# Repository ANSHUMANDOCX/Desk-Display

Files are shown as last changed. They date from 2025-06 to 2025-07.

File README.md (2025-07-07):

# Desk-Display

It is a desk display made using an E-Ink display.

---

## PARTS

I will be using the following components:

- SEEKINK 5.83 inch display  
- ESP32 WROOM  
- CH343P USB-UART  

---

## Plan

I want to make a display that can show anything, but for me, I want it to display the current **day**, **date**, and **time**, along with a **To-Do list** at the bottom.

What I want to do is have the program fetch the day, date, and time details from the Wi-Fi network the ESP32 is connected to. For the To-Do list, I will use a **website hosted on the ESP32 server** to update the data whenever I want.

The display won't be battery powered — although it can be — but I don't want that for now. It will be powered through **USB-C**. For that, I’ve also added a **switch** to disconnect the board from programming mode by turning off the CH343 IC.

# Schematic,PCB and CAD







# BOM 
---
| Product Name | Retailer | Price ($) |
|---|---|---|
| E-ink Display | LCSC | 18.16 |
| FFC, FPC Connector | LCSC | 0.79 |
| MOSFET (SI2301CDS-T1-E3) | LCSC | 0.77 |
| DIP Switch | LCSC | 0.72 |
| LDO Regulator (RT9193-33GB) | LCSC | 0.54 |
| USB to UART Converter | LCSC | 1.13 |
| WiFi Module (ESP32-WROOM-32E-N4) | LCSC | 3.89 |
| Passive Components (Grouped) | LCSC | 5.08 |
| **Subtotal (Merchandise)** | **LCSC** | **31.51** |
| Shipping | LCSC | 3.73 |
| **Total** | **LCSC** | **35.24** |
|PCB | JLCPCB | 2$ |
|Shipping |JLCPCB | 8.32$ |
|Solder Paste+ Tweezers |Electronicscomp |5$ |
| **SUB TOTAL** | |**50.56**  |

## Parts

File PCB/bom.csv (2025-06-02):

Designator | Footprint | Quantity | Value | LCSC Part #
C10, C11, C12, C13, C15, C16, C2, C5, C7, C9 | 0603 | 10 | 1UF
C14, C20, C23, C4 | 0603 | 4 | 10uF
C17, C19, C6 | 0603 | 3 | 4.7uf
C18 | 0603 | 1 | 104
C21 | 0603 | 1 | 22nF
C22 | 0603 | 1 | 47uF
C3 | 0603 | 1 | C_Small
D1, D2, D4 | D_SOD-123 | 3 | MBR0530
D3 | D_SOD-323 | 1 | 1N5819WS
D5, D6 | 0805 | 2 | LED
J3 | Hirose_FH12-24S-0.5SH_1x24-1MP_P0.50mm_Horizontal | 1 | Conn_01x24
J4 | USB_C_Receptacle_XKB_U262-16XN-4BVC11 | 1 | USB_C_Receptacle_USB2.0_16P
L1 | L_Changjiang_FNR4020S | 1 | 10uH
Q1 | SOT-23 | 1 | BSS138LT1G
Q2, Q3, Q32 | SOT-23 | 3 | SS8050
Q31 | SOT-23 | 1 | SI2301CDS-T1-E3
R1 | 0603 | 1 | 1k
R10, R35 | 0603 | 2 | NC
R11, R12, R15 | 0603 | 3 | 0r
R13, R14, R19, R3, R4, R5, R6, R8, R9 | 0603 | 9 | 10K
R16, R17 | 0603 | 2 | 5.1K
R2 | 0603 | 1 | 2.2k
R33, R34 | 0603 | 2 | 100K
R7 | 0603 | 1 | 0.47R
SW2 | SW_DIP_SPSTx02_Slide_Copal_CHS-02B_W7.62mm_P1.27mm | 1 | SW_Push_Dual_x2
SW3, SW4 | SW_Push_SPST_NO_Alps_SKRK | 2 | SW_Push
U1 | ESP32-WROOM-32D | 1 | ESP32-WROOM-32E
U2 | WCH_QFN-16-1EP_3x3mm_P0.5mm_EP1.8x1.8mm | 1 | CH343P
U3 | SOT-23-5 | 1 | RT9193-33
U4 | SOT-23-5 | 1 | ME6217C33M5G

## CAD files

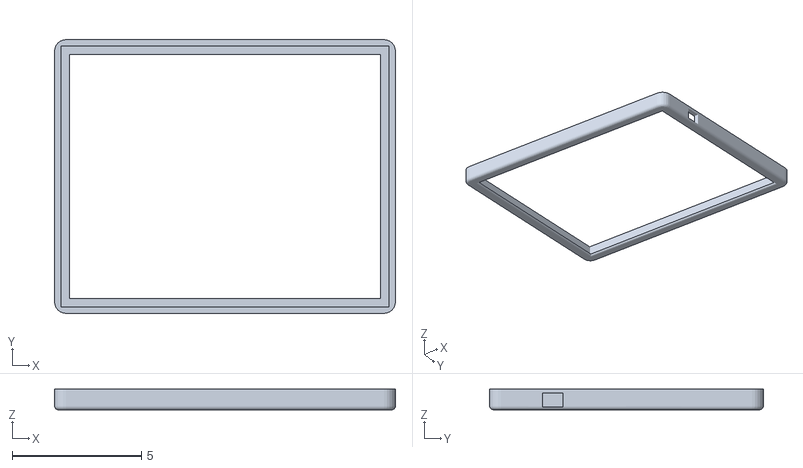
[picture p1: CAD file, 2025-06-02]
CAD/Main boy v2.obj
13.2 x 10.6 x 0.8

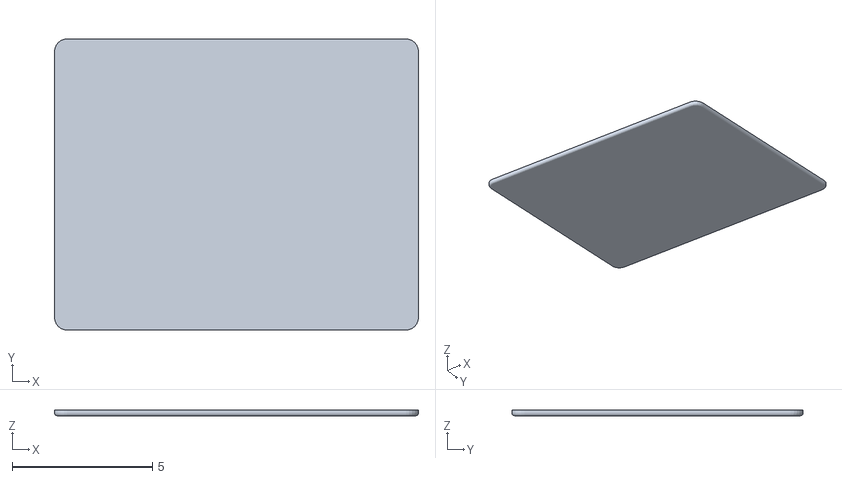
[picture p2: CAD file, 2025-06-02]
CAD/BackPLate v1.obj
13.0 x 10.4 x 0.2

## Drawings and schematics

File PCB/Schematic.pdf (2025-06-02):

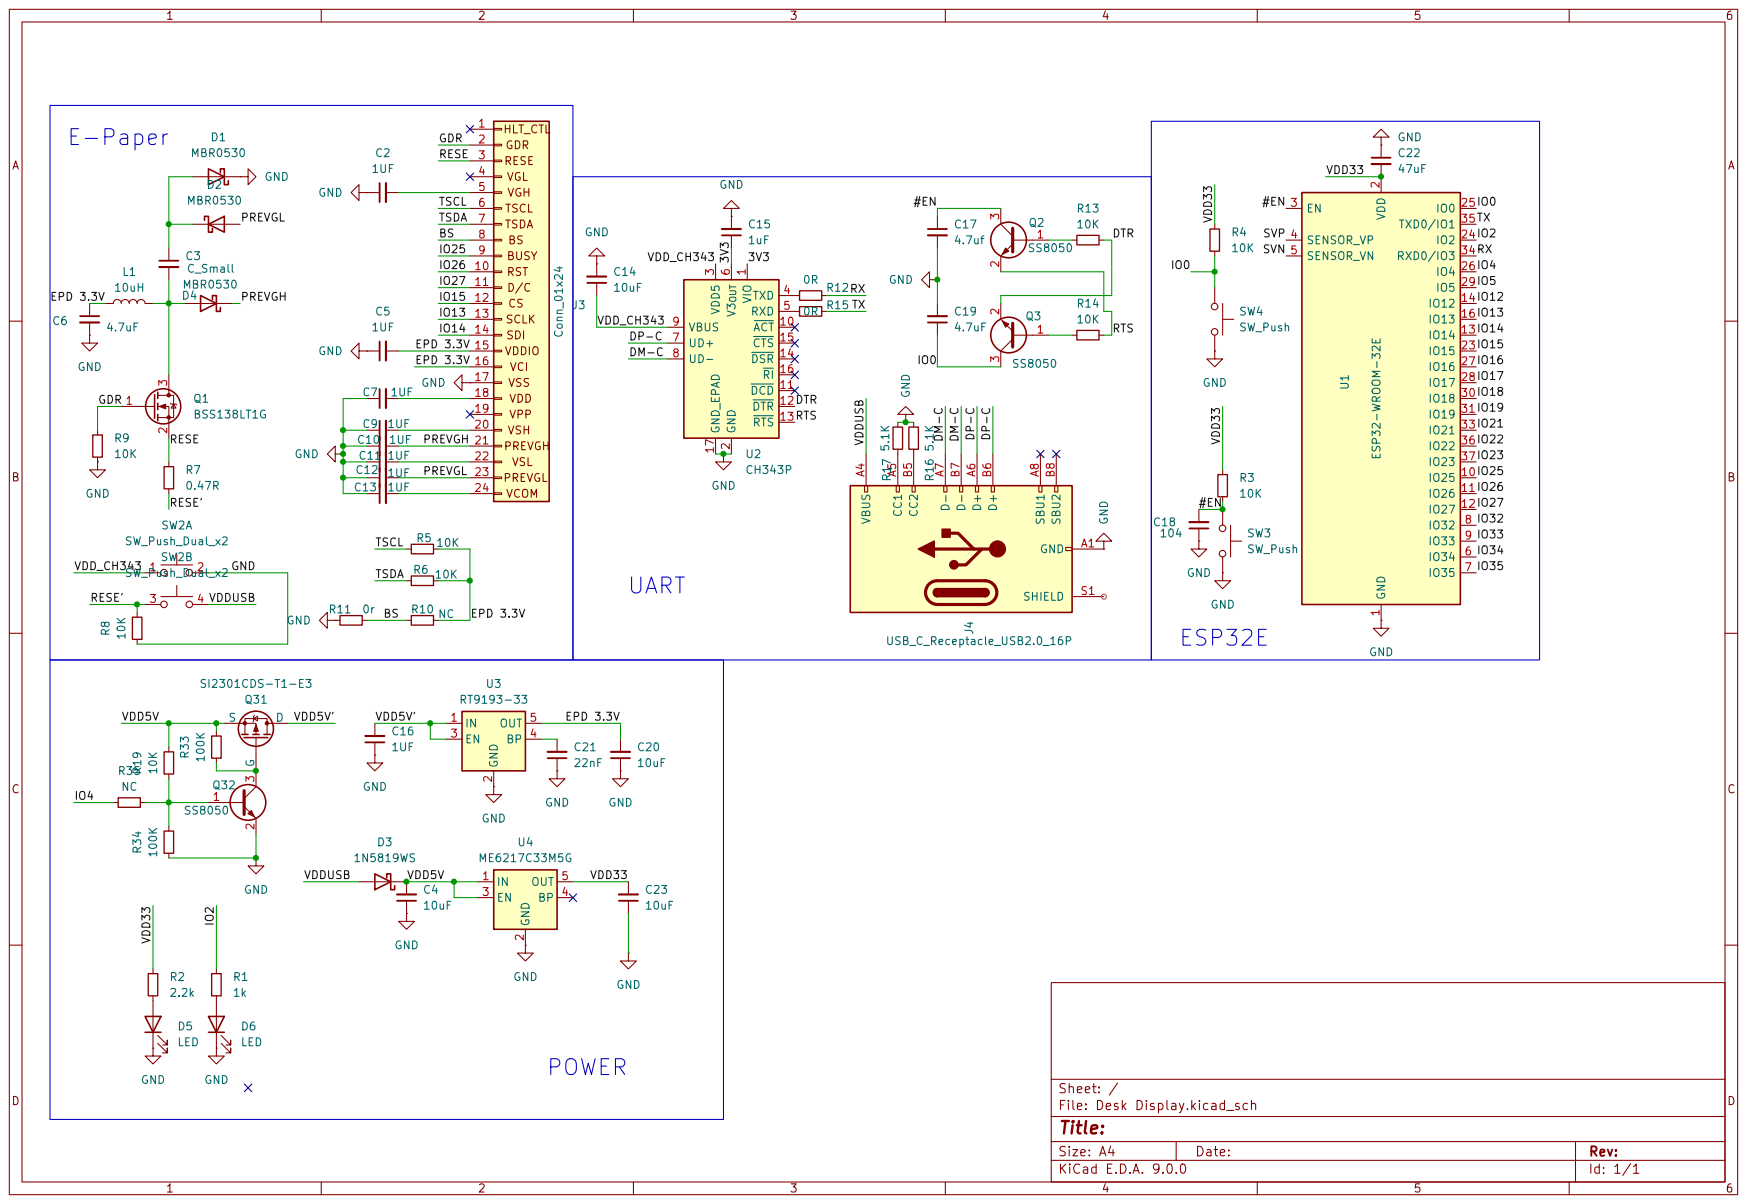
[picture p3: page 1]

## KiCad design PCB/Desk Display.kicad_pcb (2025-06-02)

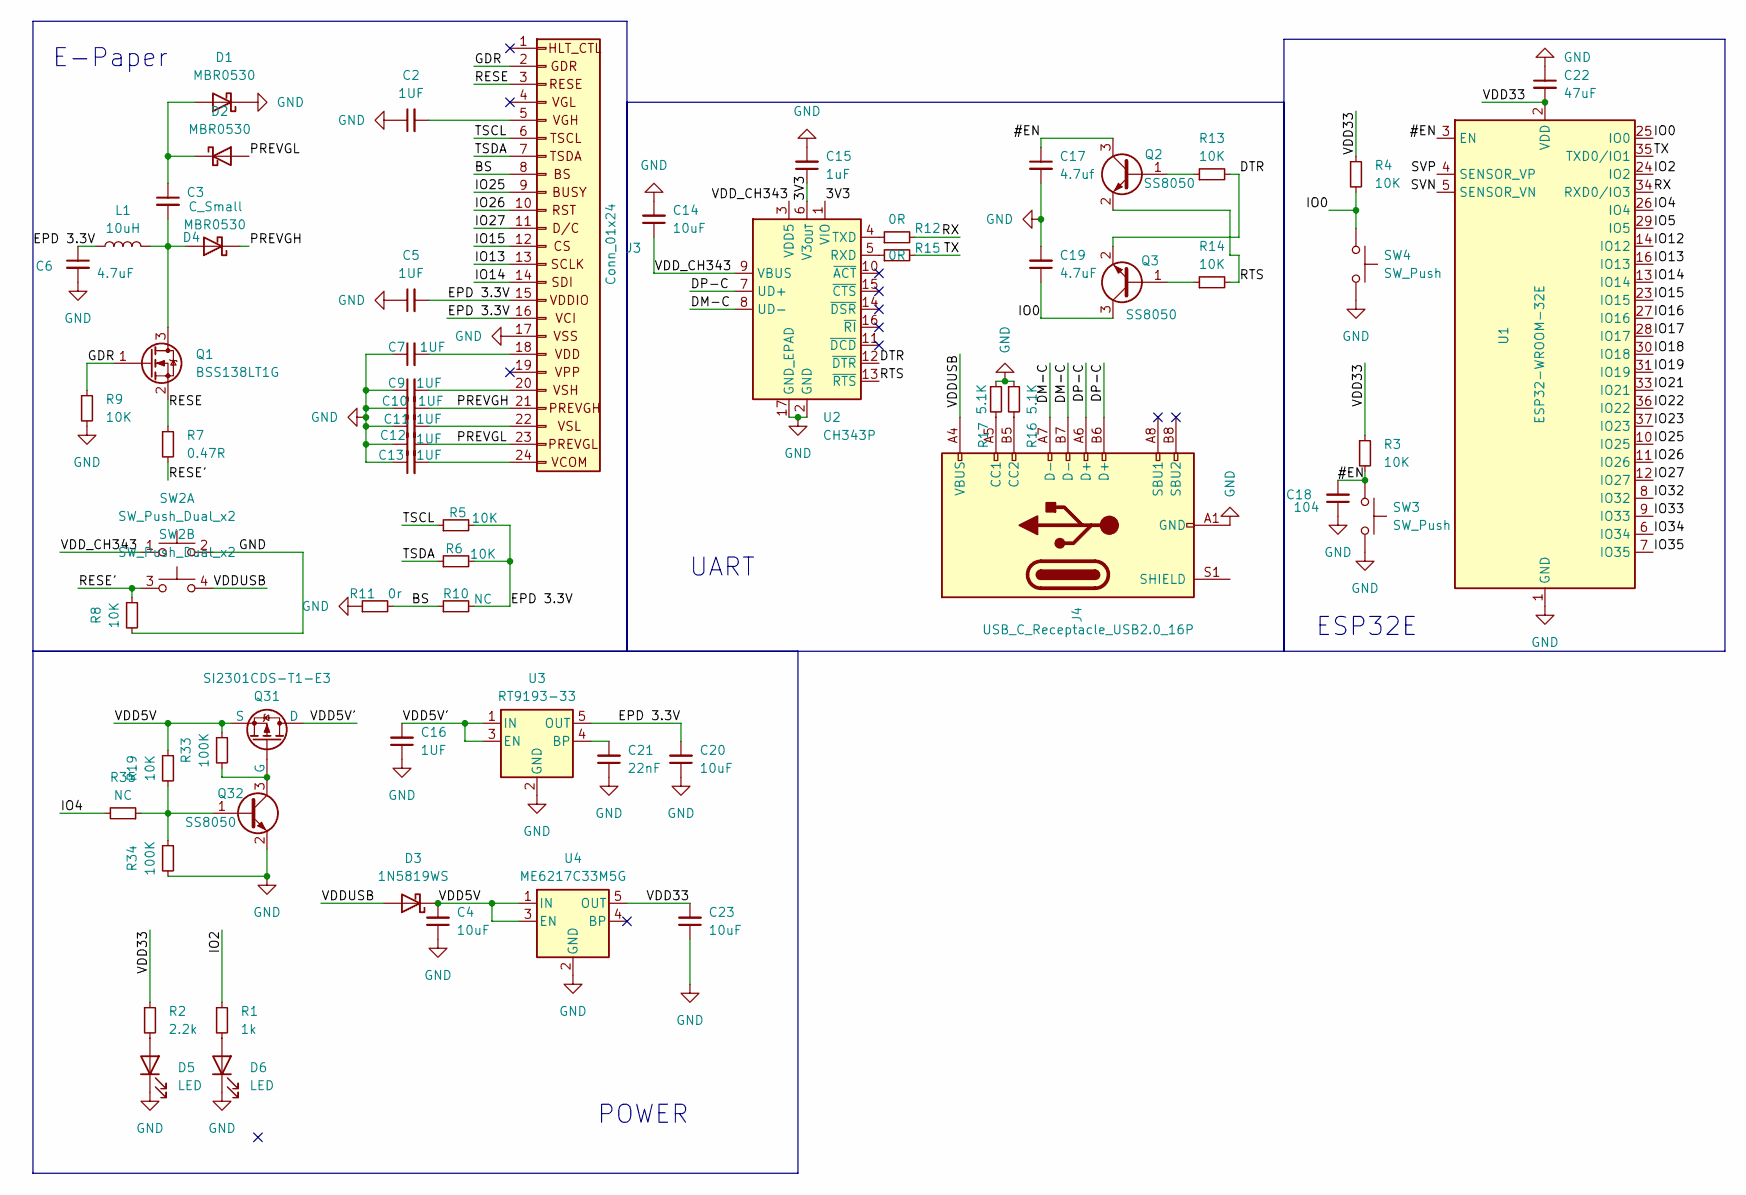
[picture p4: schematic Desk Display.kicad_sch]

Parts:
C2, C5, C7, C9, C10, C11, C12, C13, C16: 1UF; C_0603_1608Metric_Pad1.08x0.95mm_HandSolder
C3: C_Small; C_0603_1608Metric_Pad1.08x0.95mm_HandSolder
C4, C14, C20, C23: 10uF; C_0603_1608Metric_Pad1.08x0.95mm_HandSolder
C6, C19: 4.7uF; C_0603_1608Metric_Pad1.08x0.95mm_HandSolder
C15: 1uF; C_0603_1608Metric_Pad1.08x0.95mm_HandSolder
C17: 4.7uf; C_0603_1608Metric_Pad1.08x0.95mm_HandSolder
C18: 104; C_0603_1608Metric_Pad1.08x0.95mm_HandSolder
C21: 22nF; C_0603_1608Metric_Pad1.08x0.95mm_HandSolder
C22: 47uF; C_0603_1608Metric_Pad1.08x0.95mm_HandSolder
D1, D2, D4: MBR0530; D_SOD-123
D3: 1N5819WS; D_SOD-323
D5, D6: LED; LED_0805_2012Metric_Pad1.15x1.40mm_HandSolder
J3: Conn_01x24; Hirose_FH12-24S-0.5SH_1x24-1MP_P0.50mm_Horizontal
J4: USB_C_Receptacle_USB2.0_16P; USB_C_Receptacle_XKB_U262-16XN-4BVC11
L1: 10uH; L_Changjiang_FNR4020S
Q1: BSS138LT1G; SOT-23
Q2, Q3, Q32: SS8050; SOT-23
Q31: SI2301CDS-T1-E3; SOT-23
R1: 1k; R_0603_1608Metric_Pad0.98x0.95mm_HandSolder
R2: 2.2k; R_0603_1608Metric_Pad0.98x0.95mm_HandSolder
R3, R4, R5, R6, R8, R9, R13, R14, R19: 10K; R_0603_1608Metric_Pad0.98x0.95mm_HandSolder
R7: 0.47R; R_0603_1608Metric_Pad0.98x0.95mm_HandSolder
R10, R35: NC; R_0603_1608Metric_Pad0.98x0.95mm_HandSolder
R11: 0r; R_0603_1608Metric_Pad0.98x0.95mm_HandSolder
R12, R15: 0R; R_0603_1608Metric_Pad0.98x0.95mm_HandSolder
R16, R17: 5.1K; R_0603_1608Metric_Pad0.98x0.95mm_HandSolder
R33, R34: 100K; R_0603_1608Metric_Pad0.98x0.95mm_HandSolder
SW2: SW_Push_Dual_x2; SW_DIP_SPSTx02_Slide_Copal_CHS-02B_W7.62mm_P1.27mm
SW3, SW4: SW_Push; SW_Push_SPST_NO_Alps_SKRK
U1: ESP32-WROOM-32E; ESP32-WROOM-32D
U2: CH343P; WCH_QFN-16-1EP_3x3mm_P0.5mm_EP1.8x1.8mm
U3: RT9193-33; SOT-23-5
U4: ME6217C33M5G; SOT-23-5

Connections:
/3V3: C15.1, U2.1 (VIO), U2.6 (V3_{OUT})
/#EN: C17.1, C18.2, Q2.3 (C), R3.2, SW3.1, U1.3 (EN)
/BS: J3.8, R10.1, R11.2
/DM-C: J4.A7 (D-), J4.B7 (D-), U2.8 (UD-)
/DP-C: J4.A6 (D+), J4.B6 (D+), U2.7 (UD+)
/DTR: Q3.2 (E), R13.2, U2.12 (~DTR)
/EPD 3.3V: C5.2, C6.1, C20.2, J3.15, J3.16, L1.1, R5.2, R6.2, R10.2, U3.5 (OUT)
/GDR: J3.2, Q1.1 (G), R9.1
/IO0: C19.1, Q3.3 (C), R4.2, SW4.1, U1.25 (IO0)
/IO2: R1.1, U1.24 (IO2)
/IO4: R35.2, U1.26 (IO4)
/IO5: U1.29 (IO5)
/IO12: U1.14 (IO12)
/IO13: J3.13, U1.16 (IO13)
/IO14: J3.14, U1.13 (IO14)
/IO15: J3.12, U1.23 (IO15)
/IO16: U1.27 (IO16)
/IO17: U1.28 (IO17)
/IO18: U1.30 (IO18)
/IO19: U1.31 (IO19)
/IO21: U1.33 (IO21)
/IO22: U1.36 (IO22)
/IO23: U1.37 (IO23)
/IO25: J3.9, U1.10 (IO25)
/IO26: J3.10, U1.11 (IO26)
/IO27: J3.11, U1.12 (IO27)
/IO32: U1.8 (IO32)
/IO33: U1.9 (IO33)
/IO34: U1.6 (IO34)
/IO35: U1.7 (IO35)
/PREVGH: C10.2, D4.1 (K), J3.21
/PREVGL: C12.2, D2.2 (A), J3.23
/RESE: J3.3, Q1.2 (S), R7.1
/RESE': R7.2, R8.1, SW2.3 (C)
/RTS: Q2.2 (E), R14.2, U2.13 (~RTS)
/RX: R12.2, U1.34 (RXD0/IO3)
/SVN: U1.5 (SENSOR_VN)
/SVP: U1.4 (SENSOR_VP)
/TSCL: J3.6, R5.1
/TSDA: J3.7, R6.1
/TX: R15.2, U1.35 (TXD0/IO1)
/VDD5V: C4.2, D3.1 (K), Q31.3 (S), R19.1, R33.1, U4.1 (IN), U4.3 (EN)
/VDD5V': C16.2, Q31.1 (D), U3.1 (IN), U3.3 (EN)
/VDD33: C22.2, C23.2, R2.1, R3.1, R4.1, U1.2 (VDD), U4.5 (OUT)
/VDDUSB: D3.2 (A), J4.A4 (VBUS), J4.A9 (VBUS), J4.B4 (VBUS), J4.B9 (VBUS), SW2.4 (D)
/VDD_CH343: C14.1, SW2.1 (C), U2.3 (VDD5), U2.9 (VBUS)
GND: C2.1, C4.1, C5.1, C6.2, C7.1, C9.1, C10.1, C11.1, C12.1, C13.1, C14.2, C15.2, C16.1, C17.2, C18.1, C19.2, C20.1, C21.1, C22.1, C23.1, D1.1 (K), D5.1 (K), D6.1 (K), J3.17, J4.A1 (GND), J4.A12 (GND), J4.B1 (GND), J4.B12 (GND), Q32.2 (E), R8.2, R9.2, R11.1, R16.1, R17.1, R34.2, SW2.2 (D), SW3.2, SW4.2, U1.1 (GND), U1.15 (GND), U1.38 (GND), U1.39 (GND), U2.2 (GND), U2.17 (GND_EPAD), U3.2 (GND), U4.2 (GND)
unnamed: C3.1, D1.2 (A), D2.1 (K)
unnamed: C3.2, D4.2 (A), L1.2, Q1.3 (D)
unnamed: D5.2 (A), R2.2
unnamed: D6.2 (A), R1.2
unnamed: C2.2, J3.5
unnamed: C7.2, J3.18
unnamed: C9.2, J3.20
unnamed: C11.2, J3.22
unnamed: C13.2, J3.24
unnamed: J4.A5 (CC1), R17.2
unnamed: J4.B5 (CC2), R16.2
unnamed: Q2.1 (B), R13.1
unnamed: Q3.1 (B), R14.1
unnamed: Q31.2 (G), Q32.3 (C), R33.2
unnamed: Q32.1 (B), R19.2, R34.1, R35.1
unnamed: R15.1, U2.5 (RXD)
unnamed: R12.1, U2.4 (TXD)
unnamed: C21.2, U3.4 (BP)

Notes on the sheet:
UART
POWER
ESP32E
E-Paper

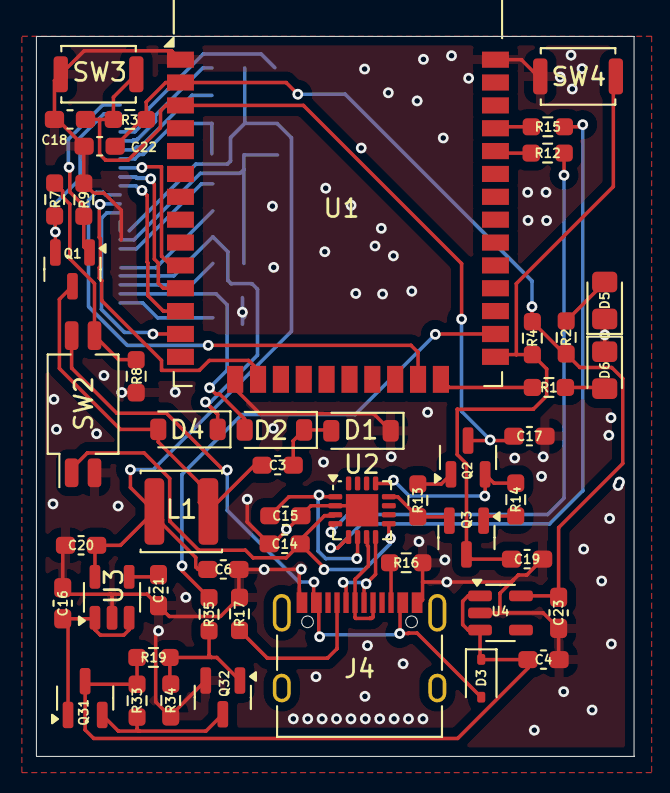
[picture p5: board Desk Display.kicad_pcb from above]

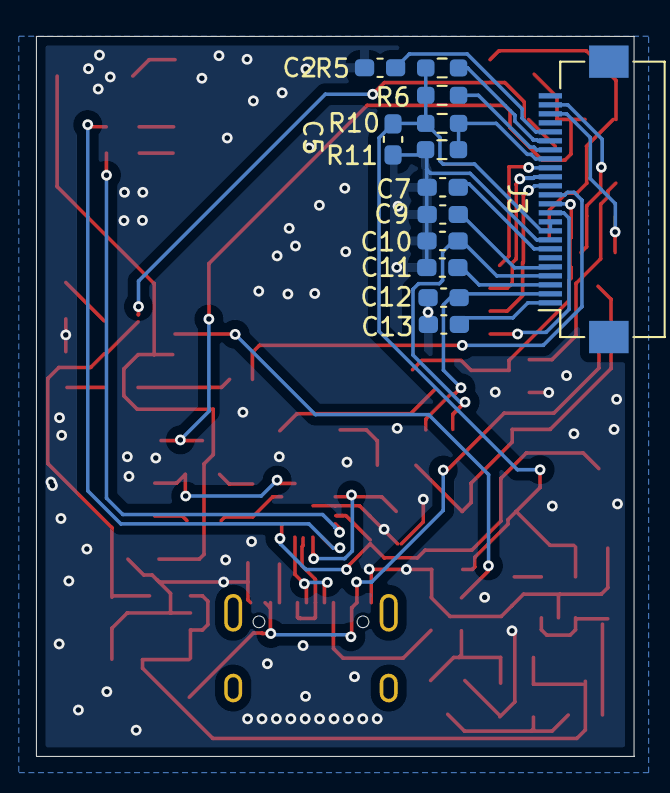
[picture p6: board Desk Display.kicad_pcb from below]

Board: 2 copper layers, 33.2 x 40.0 mm, 63 parts (13 on the bottom side), 50 nets.

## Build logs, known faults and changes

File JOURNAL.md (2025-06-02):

# **ESP32 Based Desk Display**
- **Title:** Desk Display
- **Author:** Anshuman Tripathy
- **Description:** I'm building a desk display using a 5.83-inch E-Paper screen and an ESP32. It will show the current time, day, date, and a small To-Do list.
- **Created_at:** 2025-05-25
---

## **Day 1 - 25th May: Epaper Ciruit DONE**

Today I completed the E-paper interfacing circuit. I want to use the SEEINK 5.83 inch display since it's cheap but lacks enough documentation. So, I researched and found out that Waveshare also makes the same display but it's more expensive. I compared their datasheets and found that they are almost pin-to-pin compatible. I took reference from both the docs and completed it.  

**Total time spent:** 3–4 hrs

DAY1

---

# **Day 2 - 27th May: ESP32 and UART Circuit**

Today I completed the UART and ESP32 interface. This will help in programming the ESP32. I will be using a CH343P chip and Type-C for the UART communication. I had never used the CH343P chip before, so I had to read the datasheets extensively and took reference from example circuits online.  
After this, I need to start with the power portion.  

**Time spent:** 2 hr

DAY2

---

# **Day 3 - 28th May: Power control**

I started the power portion. I used different regulator ICs for the E-paper display and ESP32. I have added a portion to turn off the display by controlling it using the ESP32.  
I had to go through many E-paper display examples to decide on the right regulator.  

**Time spent:** 1 hr

DAY3

---

# **Day 4 - 30th May: Schematic Organising and a Failed Routing attempt**

Now I completed the schematic completely and labeled the sections for better readability. Also, I assigned all the footprints.  
Majorly, I will be using 0603 for the resistors and capacitors.  
I went through LCSC to find proper footprints.  
Began with the component placing. Initially, I thought I would be making the PCB double-sided. The tracing was getting too complex, so I scrapped the idea of making the PCB double-sided. Wasted a lot of time doing so.  

**Time spent:** 4 hr

DAY 4

---

# **Day 5 - 31st May: Completed the Routing**

Started to redo the PCB from scratch. Took me 4 hrs to complete the routing. It's still not perfect — will have to change a few things and remove errors.  
I have only kept the connector and some caps associated with it on the bottom layer.  
**Time spent:** 4 hr

---

# **Day 6 - 1st June: Removed Errors from the pcb**

Completed rectifying all the errors.  
Here is the close-to-done PCB.  
DAY6

**Time spent:** 2 hr

---

# **Day 7 - 2nd June: Designed the Case and Completed the PCB**

Started with the case. Took reference from the datasheets of the display. Wanted to make it look sleek. However its not the final version since i need to get the hardware first and then will make the necessary changes
Here are the images.  

DAY7-1

Also Completed the PCB 

DAY7-2
DAY7-3

**Time spent:** 3 hr

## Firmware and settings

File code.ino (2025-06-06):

//This subject to change and not the the final code until i get the parts and prototype with them

#include <WiFi.h>
#include <time.h>
#include <GxEPD2_BW.h>
#include <Adafruit_GFX.h>

const char* ssid = "YOUR_SSID";
const char* password = "YOUR_PASSWORD";

const char* ntp = "pool.ntp.org";
const long gmt_offset_sec = 19800; // IST (+5:30)
const int day_offset_sec = 0;

#define CS   15
#define DC   27
#define RST  26
#define BUSY 25

GxEPD2_BW<GxEPD2_583, GxEPD2_583::HEIGHT> display(GxEPD2_583(CS, DC, RST, BUSY));

void setup() {
  Serial.begin(115200);
  delay(1000);

  WiFi.begin(ssid, password);
  Serial.print("Connecting to WiFi");
  while (WiFi.status() != WL_CONNECTED) {
    delay(500);
    Serial.print(".");
  }
  Serial.println(" connected!");

  configTime(gmt_offset_sec, day_offset_sec, ntp);

  display.init();
  updateTimeOnEPD();
}

void loop() {
  delay(300000); 
  updateTimeOnEPD();
}

void updateTimeOnEPD() {
  struct tm timeinfo;
  if (!getLocalTime(&timeinfo)) {
    Serial.println("Failed to get time");
    return;
  }

  char date[64];
  strftime(date, sizeof(date), "%A, %d %B %Y", &timeinfo);

  char time[16];
  strftime(time, sizeof(time), "%H:%M:%S", &timeinfo);

  display.setRotation(1); 
  display.setFullWindow();
  display.firstPage();
  do {
    display.fillScreen(GxEPD_WHITE);
    display.setTextColor(GxEPD_BLACK);

    display.setFont(&FreeMonoBold18pt7b);
    display.setCursor(20, 80);
    display.print(time);

    display.setFont(&FreeMono12pt7b);
    display.setCursor(20, 130);
    display.print(date);
  } while (display.nextPage());

  Serial.println("Updated EPD:");
  Serial.println(time);
  Serial.println(date);
}
